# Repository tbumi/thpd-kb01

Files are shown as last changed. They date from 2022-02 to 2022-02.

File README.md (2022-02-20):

# thpd-kb01

My very first mechanical keyboard designed from scratch!

## PCB

The PCB design files are made with KiCad v5.1.12.

### Features

- STM32 Microcontroller (STM32F072C8T6)
- Rotary encoder
- USB-C connector
- NHD-C12832A1Z (128x32 LCD) display (not confirmed working)

## Case

The case files are made with Inkscape. They are available in the `case/` subdirectory.

## License

Licensed under the CERN Open Hardware Licence Version 2 - Strongly Reciprocal. A copy of
the license is included in this repository.

## Firmware

This keyboard uses the QMK firmware. See the firmware in the fork here:
https://github.com/tbumi/qmk_firmware/tree/thpd-kb01/keyboards/thpd_kb01

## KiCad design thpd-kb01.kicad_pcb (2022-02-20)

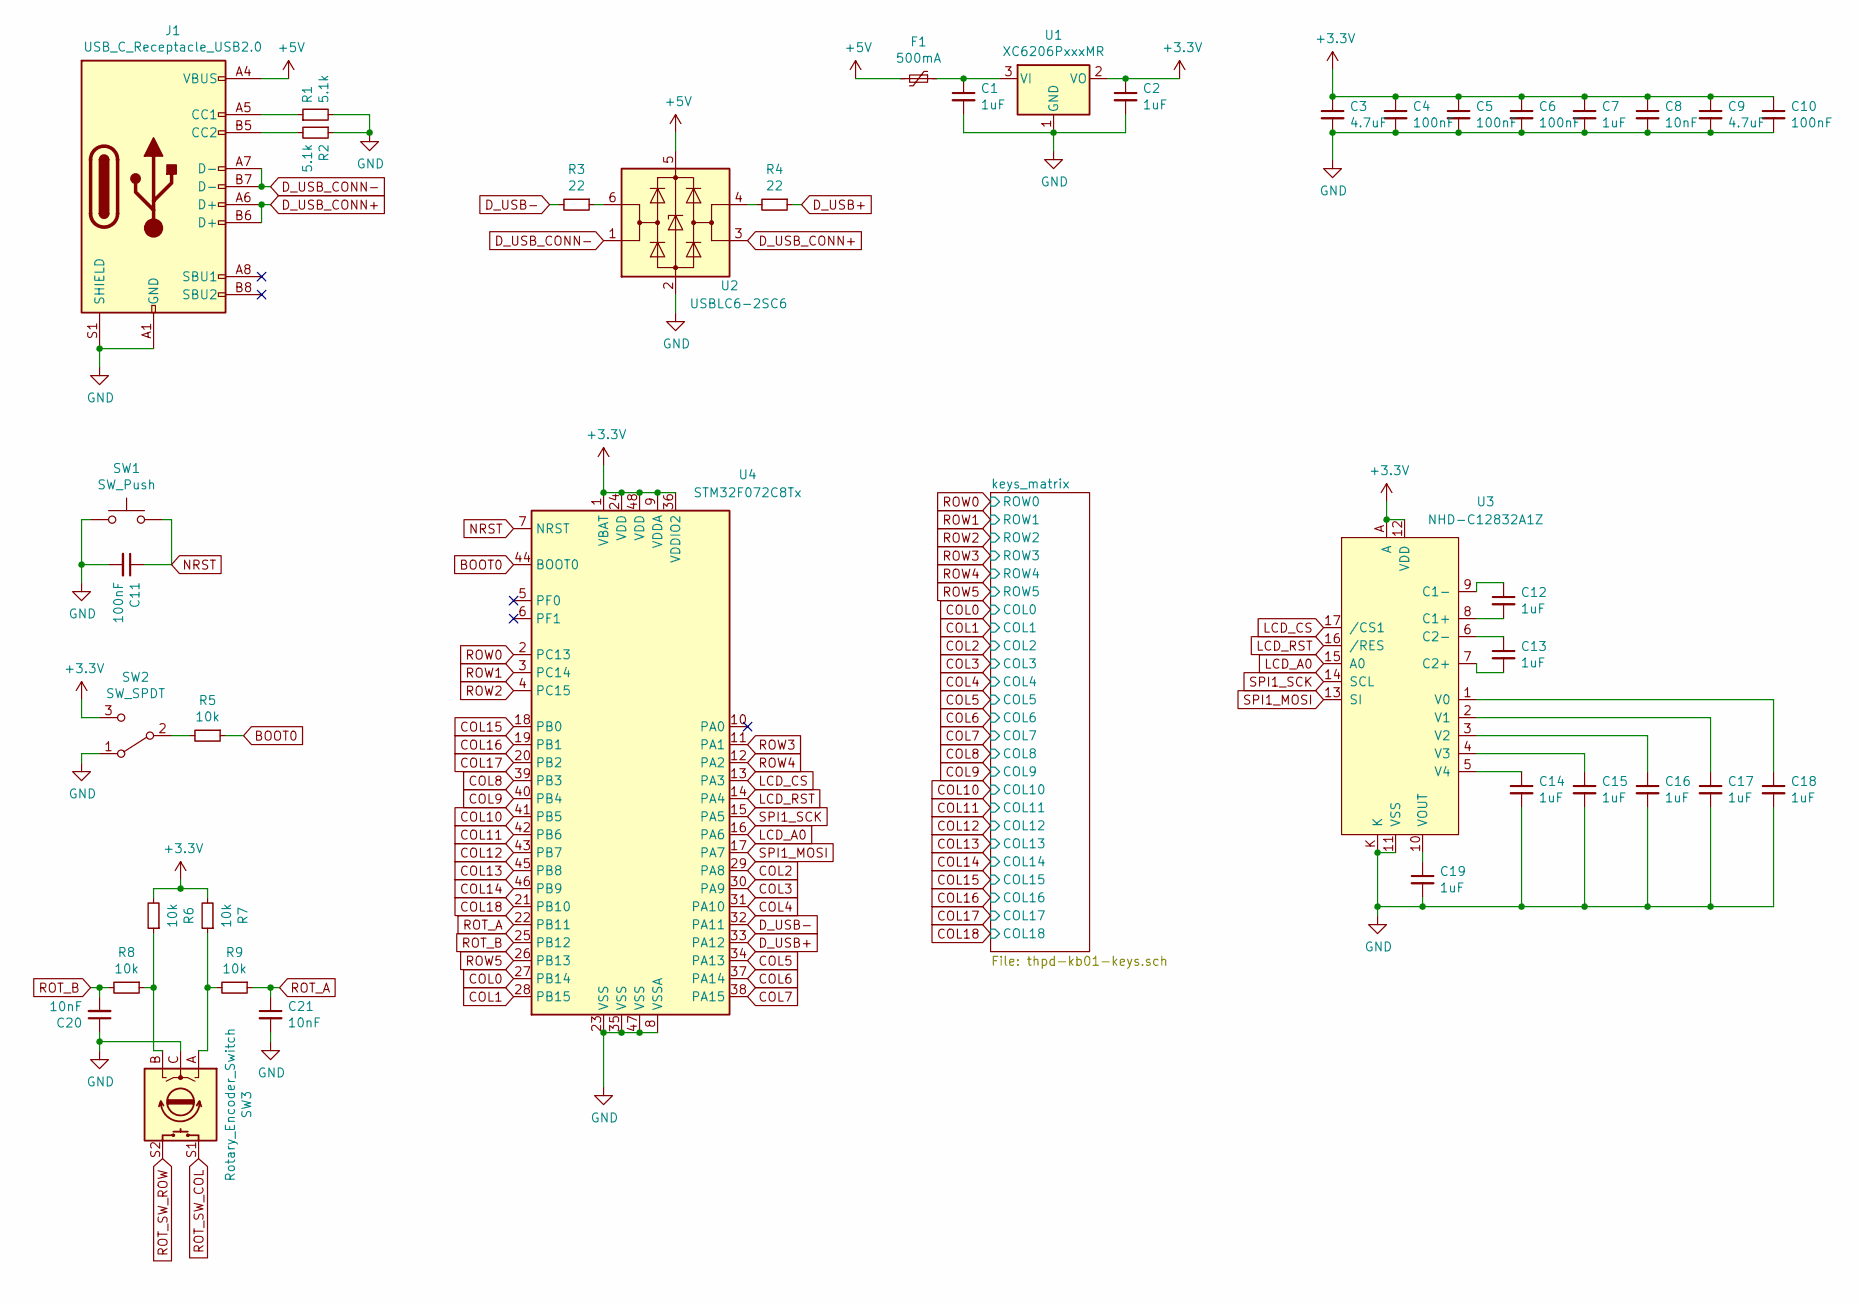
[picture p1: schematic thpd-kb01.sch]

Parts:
C1, C2, C7, C12, C13, C14, C15, C16, C17, C18, C19: 1uF; C_0402_1005Metric; LCSC Part # C52923
C3, C9: 4.7uF; C_0402_1005Metric; LCSC Part # C23733
C4, C5, C6, C10, C11: 100nF; C_0402_1005Metric; LCSC Part # C1525
C8, C20, C21: 10nF; C_0402_1005Metric; LCSC Part # C15195
F1: 500mA; Fuse_0603_1608Metric; LCSC Part # C135321
J1: USB_C_Receptacle_USB2.0; USB_C_Receptacle_HRO_TYPE-C-31-M-12; LCSC Part # C165948
R1, R2: 5.1k; R_0402_1005Metric; LCSC Part # C25905
R3, R4: 22; R_0402_1005Metric; LCSC Part # C25092
R5, R6, R7, R8, R9: 10k; R_0603_1608Metric; LCSC Part # C25804
SW1: SW_Push; SW_Push_SPST_NO_Alps_SKRK; LCSC Part # C202388
SW2: SW_SPDT; SW_SPDT_K3-1296S-E1; LCSC Part # C128955
SW3: Rotary_Encoder_Switch; RotaryEncoder_Alps_EC11E-Switch_Vertical_H20mm
U1: XC6206PxxxMR; SOT-23; LCSC Part # C5446
U2: USBLC6-2SC6; SOT-23-6; LCSC Part # C2827654
U3: NHD-C12832A1Z
U4: STM32F072C8Tx; LQFP-48_7x7mm_P0.5mm

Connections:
+3V3: C2.1, C3.1, C4.1, C5.1, C6.1, C7.1, C8.1, C9.1, C10.1, R6.2, R7.2, SW2.3 (C), U1.2 (VO), U3.12 (VDD), U3.A, U4.1 (VBAT), U4.9 (VDDA), U4.24 (VDD), U4.36 (VDDIO2), U4.48 (VDD)
+5V: F1.2, J1.A4 (VBUS), J1.A9 (VBUS), J1.B4 (VBUS), J1.B9 (VBUS), U2.5 (VBUS)
BOOT0: R5.1, U4.44 (BOOT0)
COL0: U4.27 (PB14); also elsewhere on the board
COL1: U4.28 (PB15); also elsewhere on the board
COL2: U4.29 (PA8); also elsewhere on the board
COL3: U4.30 (PA9); also elsewhere on the board
COL4: U4.31 (PA10); also elsewhere on the board
COL5: U4.34 (PA13); also elsewhere on the board
COL6: U4.37 (PA14); also elsewhere on the board
COL7: U4.38 (PA15); also elsewhere on the board
COL8: U4.39 (PB3); also elsewhere on the board
COL9: U4.40 (PB4); also elsewhere on the board
COL10: U4.41 (PB5); also elsewhere on the board
COL11: U4.42 (PB6); also elsewhere on the board
COL12: U4.43 (PB7); also elsewhere on the board
COL13: U4.45 (PB8); also elsewhere on the board
COL14: U4.46 (PB9); also elsewhere on the board
COL15: U4.18 (PB0); also elsewhere on the board
COL16: U4.19 (PB1); also elsewhere on the board
COL17: U4.20 (PB2); also elsewhere on the board
COL18: SW3.S1, U4.21 (PB10); also elsewhere on the board
D_USB+: R4.1, U4.33 (PA12)
D_USB-: R3.2, U4.32 (PA11)
D_USB_CONN+: J1.A6 (D+), J1.B6 (D+), U2.3 (I/O2)
D_USB_CONN-: J1.A7 (D-), J1.B7 (D-), U2.1 (I/O1)
GND: C1.2, C2.2, C3.2, C4.2, C5.2, C6.2, C7.2, C8.2, C9.2, C10.2, C11.2, C14.2, C15.2, C16.2, C17.2, C18.2, C19.2, C20.1, C21.2, J1.A1 (GND), J1.A12 (GND), J1.B1 (GND), J1.B12 (GND), J1.S1 (SHIELD), R1.2, R2.1, SW1.1, SW2.1 (A), SW3.C, U1.1 (GND), U2.2 (GND), U3.11 (VSS), U3.K, U4.8 (VSSA), U4.23 (VSS), U4.35 (VSS), U4.47 (VSS)
LCD_A0: U3.15 (A0), U4.16 (PA6)
LCD_CS: U3.17 (/CS1), U4.13 (PA3)
LCD_RST: U3.16 (/RES), U4.14 (PA4)
NRST: C11.1, SW1.2, U4.7 (NRST)
unnamed: C1.1, F1.1, U1.3 (VI)
unnamed: C12.1, U3.9 (C1-)
unnamed: C12.2, U3.8 (C1+)
unnamed: C13.1, U3.6 (C2-)
unnamed: C13.2, U3.7 (C2+)
unnamed: C14.1, U3.5 (V4)
unnamed: C15.1, U3.4 (V3)
unnamed: C16.1, U3.3 (V2)
unnamed: C17.1, U3.2 (V1)
unnamed: C18.1, U3.1 (V0)
unnamed: C19.1, U3.10 (VOUT)
unnamed: J1.A5 (CC1), R1.1
unnamed: J1.B5 (CC2), R2.2
unnamed: R3.1, U2.6 (I/O1)
unnamed: R4.2, U2.4 (I/O2)
unnamed: R5.2, SW2.2 (B)
unnamed: R6.1, R8.1, SW3.B
unnamed: R7.1, R9.2, SW3.A
ROT_A: C21.1, R9.1, U4.22 (PB11)
ROT_B: C20.2, R8.2, U4.25 (PB12)
ROT_SW_ROW: SW3.S2; also elsewhere on the board
ROW0: U4.2 (PC13); also elsewhere on the board
ROW1: U4.3 (PC14); also elsewhere on the board
ROW2: U4.4 (PC15); also elsewhere on the board
ROW3: U4.11 (PA1); also elsewhere on the board
ROW4: U4.12 (PA2); also elsewhere on the board
ROW5: U4.26 (PB13); also elsewhere on the board
SPI1_MOSI: U3.13 (SI), U4.17 (PA7)
SPI1_SCK: U3.14 (SCL), U4.15 (PA5)

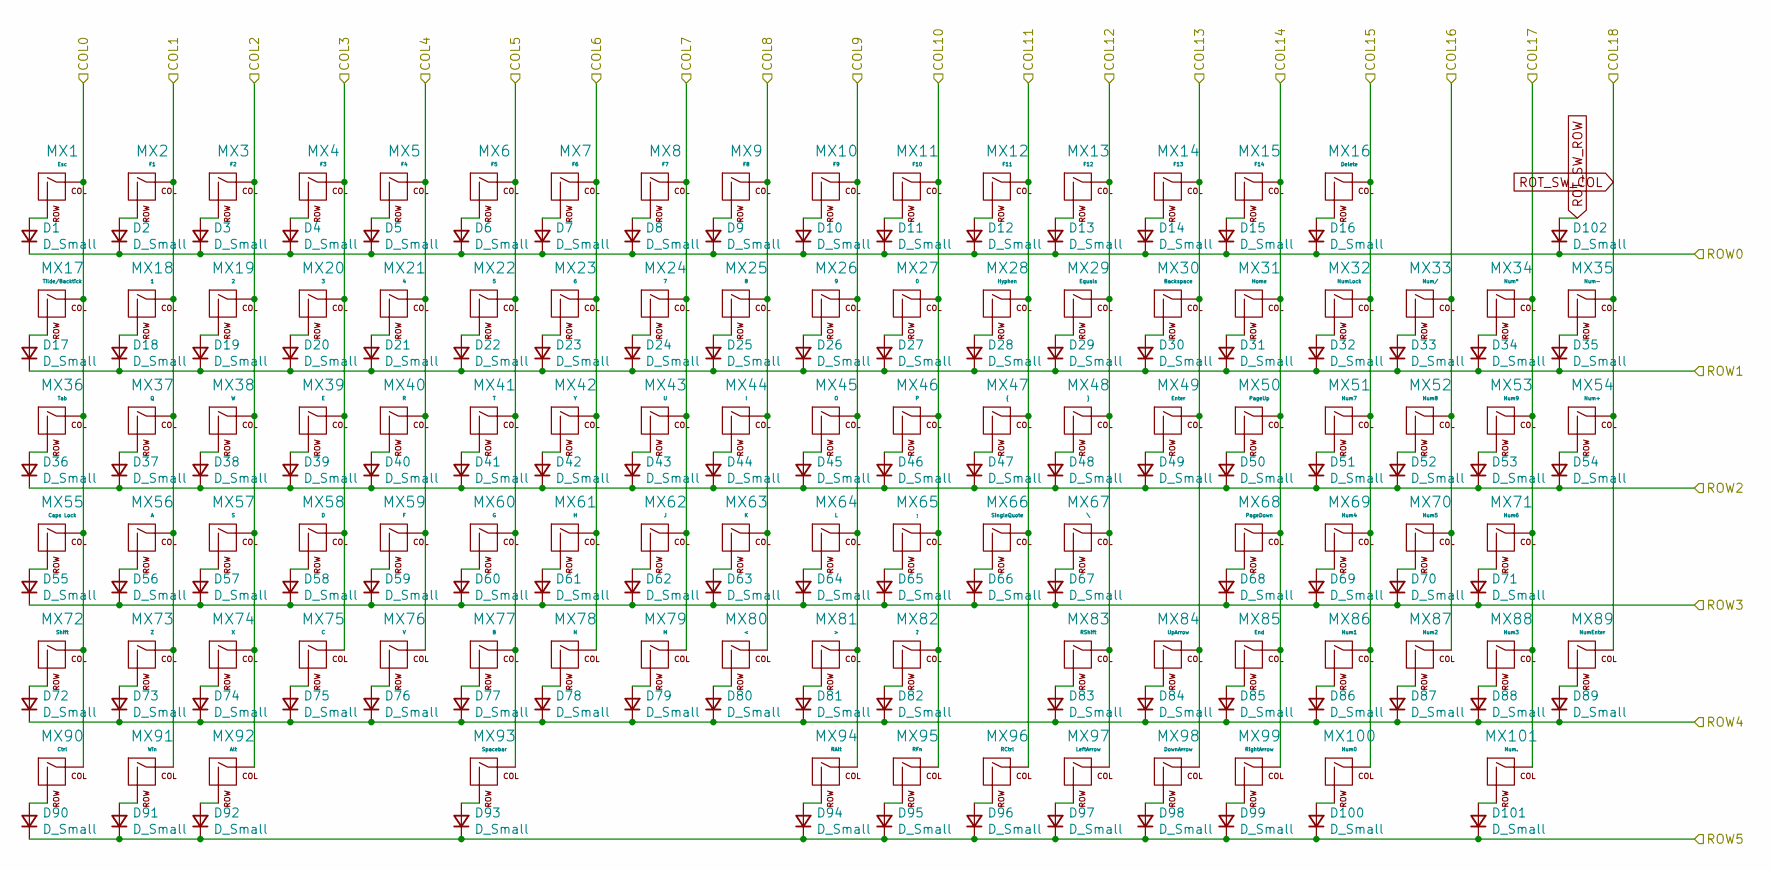
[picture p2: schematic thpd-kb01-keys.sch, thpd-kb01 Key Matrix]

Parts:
D1, D2, D3, D4, D5, D6, D7, D8, D9, D10, D11, D12, D13, D14, D15, D16, D17, D18, D19, D20, D21, D22, D23, D24, D25, D26, D27, D28, D29, D30, D31, D32, D33, D34, D35, D36, D37, D38, D39, D40, D41, D42, D43, D44, D45, D46, D47, D48, D49, D50, D51, D52, D53, D54, D55, D56, D57, D58, D59, D60, D61, D62, D63, D64, D65, D66, D67, D68, D69, D70, D71, D72, D73, D74, D75, D76, D77, D78, D79, D80, D81, D82, D83, D84, D85, D86, D87, D88, D89, D90, D91, D92, D93, D94, D95, D96, D97, D98, D99, D100, D101, D102: D_Small; D_SOD-123; LCSC Part # C81598
MX1: Esc; SW_Cherry_MX_1.00u_Plate
MX2: F1; SW_Cherry_MX_1.00u_Plate
MX3: F2; SW_Cherry_MX_1.00u_Plate
MX4: F3; SW_Cherry_MX_1.00u_Plate
MX5: F4; SW_Cherry_MX_1.00u_Plate
MX6: F5; SW_Cherry_MX_1.00u_Plate
MX7: F6; SW_Cherry_MX_1.00u_Plate
MX8: F7; SW_Cherry_MX_1.00u_Plate
MX9: F8; SW_Cherry_MX_1.00u_Plate
MX10: F9; SW_Cherry_MX_1.00u_Plate
MX11: F10; SW_Cherry_MX_1.00u_Plate
MX12: F11; SW_Cherry_MX_1.00u_Plate
MX13: F12; SW_Cherry_MX_1.00u_Plate
MX14: F13; SW_Cherry_MX_1.00u_Plate
MX15: F14; SW_Cherry_MX_1.00u_Plate
MX16: Delete; SW_Cherry_MX_1.00u_Plate
MX17: Tilde/Backtick; SW_Cherry_MX_1.00u_Plate
MX18: 1; SW_Cherry_MX_1.00u_Plate
MX19: 2; SW_Cherry_MX_1.00u_Plate
MX20: 3; SW_Cherry_MX_1.00u_Plate
MX21: 4; SW_Cherry_MX_1.00u_Plate
MX22: 5; SW_Cherry_MX_1.00u_Plate
MX23: 6; SW_Cherry_MX_1.00u_Plate
MX24: 7; SW_Cherry_MX_1.00u_Plate
MX25: 8; SW_Cherry_MX_1.00u_Plate
MX26: 9; SW_Cherry_MX_1.00u_Plate
MX27: 0; SW_Cherry_MX_1.00u_Plate
MX28: Hyphen; SW_Cherry_MX_1.00u_Plate
MX29: Equals; SW_Cherry_MX_1.00u_Plate
MX30: Backspace; SW_Cherry_MX_2.00u_Plate
MX31: Home; SW_Cherry_MX_1.00u_Plate
MX32: NumLock; SW_Cherry_MX_1.00u_Plate
MX33: Num/; SW_Cherry_MX_1.00u_Plate
MX34: Num*; SW_Cherry_MX_1.00u_Plate
MX35: Num-; SW_Cherry_MX_1.00u_Plate
MX36: Tab; SW_Cherry_MX_1.50u_Plate
MX37: Q; SW_Cherry_MX_1.00u_Plate
MX38: W; SW_Cherry_MX_1.00u_Plate
MX39: E; SW_Cherry_MX_1.00u_Plate
MX40: R; SW_Cherry_MX_1.00u_Plate
MX41: T; SW_Cherry_MX_1.00u_Plate
MX42: Y; SW_Cherry_MX_1.00u_Plate
MX43: U; SW_Cherry_MX_1.00u_Plate
MX44: I; SW_Cherry_MX_1.00u_Plate
MX45: O; SW_Cherry_MX_1.00u_Plate
MX46: P; SW_Cherry_MX_1.00u_Plate
MX47: {; SW_Cherry_MX_1.00u_Plate
MX48: }; SW_Cherry_MX_1.00u_Plate
MX49: Enter; SW_Cherry_MX_ISOEnter_Plate
MX50: PageUp; SW_Cherry_MX_1.00u_Plate
MX51: Num7; SW_Cherry_MX_1.00u_Plate
MX52: Num8; SW_Cherry_MX_1.00u_Plate
MX53: Num9; SW_Cherry_MX_1.00u_Plate
MX54: Num+; SW_Cherry_MX_2.00u_Vertical_Plate
MX55: Caps Lock; SW_Cherry_MX_1.75u_Plate
MX56: A; SW_Cherry_MX_1.00u_Plate
MX57: S; SW_Cherry_MX_1.00u_Plate
MX58: D; SW_Cherry_MX_1.00u_Plate
MX59: F; SW_Cherry_MX_1.00u_Plate
MX60: G; SW_Cherry_MX_1.00u_Plate
MX61: H; SW_Cherry_MX_1.00u_Plate
MX62: J; SW_Cherry_MX_1.00u_Plate
MX63: K; SW_Cherry_MX_1.00u_Plate
MX64: L; SW_Cherry_MX_1.00u_Plate
MX65: ;; SW_Cherry_MX_1.00u_Plate
MX66: SingleQuote; SW_Cherry_MX_1.00u_Plate
MX67: \\; SW_Cherry_MX_1.00u_Plate
MX68: PageDown; SW_Cherry_MX_1.00u_Plate
MX69: Num4; SW_Cherry_MX_1.00u_Plate
MX70: Num5; SW_Cherry_MX_1.00u_Plate
MX71: Num6; SW_Cherry_MX_1.00u_Plate
MX72: Shift; SW_Cherry_MX_2.25u_Plate
MX73: Z; SW_Cherry_MX_1.00u_Plate
MX74: X; SW_Cherry_MX_1.00u_Plate
MX75: C; SW_Cherry_MX_1.00u_Plate
MX76: V; SW_Cherry_MX_1.00u_Plate
MX77: B; SW_Cherry_MX_1.00u_Plate
MX78: N; SW_Cherry_MX_1.00u_Plate
MX79: M; SW_Cherry_MX_1.00u_Plate
MX80: <; SW_Cherry_MX_1.00u_Plate
MX81: >; SW_Cherry_MX_1.00u_Plate
MX82: ?; SW_Cherry_MX_1.00u_Plate
MX83: RShift; SW_Cherry_MX_1.75u_Plate
MX84: UpArrow; SW_Cherry_MX_1.00u_Plate
MX85: End; SW_Cherry_MX_1.00u_Plate
MX86: Num1; SW_Cherry_MX_1.00u_Plate
MX87: Num2; SW_Cherry_MX_1.00u_Plate
MX88: Num3; SW_Cherry_MX_1.00u_Plate
MX89: NumEnter; SW_Cherry_MX_2.00u_Vertical_Plate
MX90: Ctrl; SW_Cherry_MX_1.25u_Plate
MX91: Win; SW_Cherry_MX_1.25u_Plate
MX92: Alt; SW_Cherry_MX_1.25u_Plate
MX93: Spacebar; SW_Cherry_MX_6.25u_Plate
MX94: RAlt; SW_Cherry_MX_1.00u_Plate
MX95: RFn; SW_Cherry_MX_1.00u_Plate
MX96: RCtrl; SW_Cherry_MX_1.00u_Plate
MX97: LeftArrow; SW_Cherry_MX_1.00u_Plate
MX98: DownArrow; SW_Cherry_MX_1.00u_Plate
MX99: RightArrow; SW_Cherry_MX_1.00u_Plate
MX100: Num0; SW_Cherry_MX_2.00u_Plate
MX101: Num.; SW_Cherry_MX_1.00u_Plate

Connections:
COL0: MX1.1 (COL), MX17.1 (COL), MX36.1 (COL), MX55.1 (COL), MX72.1 (COL), MX90.1 (COL); also elsewhere on the board
COL1: MX2.1 (COL), MX18.1 (COL), MX37.1 (COL), MX56.1 (COL), MX73.1 (COL), MX91.1 (COL); also elsewhere on the board
COL2: MX3.1 (COL), MX19.1 (COL), MX38.1 (COL), MX57.1 (COL), MX74.1 (COL), MX92.1 (COL); also elsewhere on the board
COL3: MX4.1 (COL), MX20.1 (COL), MX39.1 (COL), MX58.1 (COL), MX75.1 (COL); also elsewhere on the board
COL4: MX5.1 (COL), MX21.1 (COL), MX40.1 (COL), MX59.1 (COL), MX76.1 (COL); also elsewhere on the board
COL5: MX6.1 (COL), MX22.1 (COL), MX41.1 (COL), MX60.1 (COL), MX77.1 (COL), MX93.1 (COL); also elsewhere on the board
COL6: MX7.1 (COL), MX23.1 (COL), MX42.1 (COL), MX61.1 (COL), MX78.1 (COL); also elsewhere on the board
COL7: MX8.1 (COL), MX24.1 (COL), MX43.1 (COL), MX62.1 (COL), MX79.1 (COL); also elsewhere on the board
COL8: MX9.1 (COL), MX25.1 (COL), MX44.1 (COL), MX63.1 (COL), MX80.1 (COL); also elsewhere on the board
COL9: MX10.1 (COL), MX26.1 (COL), MX45.1 (COL), MX64.1 (COL), MX81.1 (COL), MX94.1 (COL); also elsewhere on the board
COL10: MX11.1 (COL), MX27.1 (COL), MX46.1 (COL), MX65.1 (COL), MX82.1 (COL), MX95.1 (COL); also elsewhere on the board
COL11: MX12.1 (COL), MX28.1 (COL), MX47.1 (COL), MX66.1 (COL), MX96.1 (COL); also elsewhere on the board
COL12: MX13.1 (COL), MX29.1 (COL), MX48.1 (COL), MX67.1 (COL), MX83.1 (COL), MX97.1 (COL); also elsewhere on the board
COL13: MX14.1 (COL), MX30.1 (COL), MX49.1 (COL), MX84.1 (COL), MX98.1 (COL); also elsewhere on the board
COL14: MX15.1 (COL), MX31.1 (COL), MX50.1 (COL), MX68.1 (COL), MX85.1 (COL), MX99.1 (COL); also elsewhere on the board
COL15: MX16.1 (COL), MX32.1 (COL), MX51.1 (COL), MX69.1 (COL), MX86.1 (COL), MX100.1 (COL); also elsewhere on the board
COL16: MX33.1 (COL), MX52.1 (COL), MX70.1 (COL), MX87.1 (COL); also elsewhere on the board
COL17: MX34.1 (COL), MX53.1 (COL), MX71.1 (COL), MX88.1 (COL), MX101.1 (COL); also elsewhere on the board
COL18: MX35.1 (COL), MX54.1 (COL), MX89.1 (COL); also elsewhere on the board
unnamed: D1.2 (A), MX1.2 (ROW)
unnamed: D2.2 (A), MX2.2 (ROW)
unnamed: D3.2 (A), MX3.2 (ROW)
unnamed: D4.2 (A), MX4.2 (ROW)
unnamed: D5.2 (A), MX5.2 (ROW)
unnamed: D6.2 (A), MX6.2 (ROW)
unnamed: D7.2 (A), MX7.2 (ROW)
unnamed: D8.2 (A), MX8.2 (ROW)
unnamed: D9.2 (A), MX9.2 (ROW)
unnamed: D10.2 (A), MX10.2 (ROW)
unnamed: D11.2 (A), MX11.2 (ROW)
unnamed: D12.2 (A), MX12.2 (ROW)
unnamed: D13.2 (A), MX13.2 (ROW)
unnamed: D14.2 (A), MX14.2 (ROW)
unnamed: D15.2 (A), MX15.2 (ROW)
unnamed: D16.2 (A), MX16.2 (ROW)
unnamed: D17.2 (A), MX17.2 (ROW)
unnamed: D18.2 (A), MX18.2 (ROW)
unnamed: D19.2 (A), MX19.2 (ROW)
unnamed: D20.2 (A), MX20.2 (ROW)
unnamed: D21.2 (A), MX21.2 (ROW)
unnamed: D22.2 (A), MX22.2 (ROW)
unnamed: D23.2 (A), MX23.2 (ROW)
unnamed: D24.2 (A), MX24.2 (ROW)
unnamed: D25.2 (A), MX25.2 (ROW)
unnamed: D26.2 (A), MX26.2 (ROW)
unnamed: D27.2 (A), MX27.2 (ROW)
unnamed: D28.2 (A), MX28.2 (ROW)
unnamed: D29.2 (A), MX29.2 (ROW)
unnamed: D30.2 (A), MX30.2 (ROW)
unnamed: D31.2 (A), MX31.2 (ROW)
unnamed: D32.2 (A), MX32.2 (ROW)
unnamed: D33.2 (A), MX33.2 (ROW)
unnamed: D34.2 (A), MX34.2 (ROW)
unnamed: D35.2 (A), MX35.2 (ROW)
unnamed: D36.2 (A), MX36.2 (ROW)
unnamed: D37.2 (A), MX37.2 (ROW)
unnamed: D38.2 (A), MX38.2 (ROW)
unnamed: D39.2 (A), MX39.2 (ROW)
unnamed: D40.2 (A), MX40.2 (ROW)
unnamed: D41.2 (A), MX41.2 (ROW)
unnamed: D42.2 (A), MX42.2 (ROW)
unnamed: D43.2 (A), MX43.2 (ROW)
unnamed: D44.2 (A), MX44.2 (ROW)
unnamed: D45.2 (A), MX45.2 (ROW)
unnamed: D46.2 (A), MX46.2 (ROW)
unnamed: D47.2 (A), MX47.2 (ROW)
unnamed: D48.2 (A), MX48.2 (ROW)
unnamed: D49.2 (A), MX49.2 (ROW)
unnamed: D50.2 (A), MX50.2 (ROW)
unnamed: D51.2 (A), MX51.2 (ROW)
unnamed: D52.2 (A), MX52.2 (ROW)
unnamed: D53.2 (A), MX53.2 (ROW)
unnamed: D54.2 (A), MX54.2 (ROW)
unnamed: D55.2 (A), MX55.2 (ROW)
unnamed: D56.2 (A), MX56.2 (ROW)
unnamed: D57.2 (A), MX57.2 (ROW)
unnamed: D58.2 (A), MX58.2 (ROW)
unnamed: D59.2 (A), MX59.2 (ROW)
unnamed: D60.2 (A), MX60.2 (ROW)
unnamed: D61.2 (A), MX61.2 (ROW)
unnamed: D62.2 (A), MX62.2 (ROW)
unnamed: D63.2 (A), MX63.2 (ROW)
unnamed: D64.2 (A), MX64.2 (ROW)
unnamed: D65.2 (A), MX65.2 (ROW)
unnamed: D66.2 (A), MX66.2 (ROW)
unnamed: D67.2 (A), MX67.2 (ROW)
unnamed: D68.2 (A), MX68.2 (ROW)
unnamed: D69.2 (A), MX69.2 (ROW)
unnamed: D70.2 (A), MX70.2 (ROW)
unnamed: D71.2 (A), MX71.2 (ROW)
unnamed: D72.2 (A), MX72.2 (ROW)
unnamed: D73.2 (A), MX73.2 (ROW)
unnamed: D74.2 (A), MX74.2 (ROW)
unnamed: D75.2 (A), MX75.2 (ROW)
unnamed: D76.2 (A), MX76.2 (ROW)
unnamed: D77.2 (A), MX77.2 (ROW)
unnamed: D78.2 (A), MX78.2 (ROW)
unnamed: D79.2 (A), MX79.2 (ROW)
unnamed: D80.2 (A), MX80.2 (ROW)
unnamed: D81.2 (A), MX81.2 (ROW)
unnamed: D82.2 (A), MX82.2 (ROW)
unnamed: D83.2 (A), MX83.2 (ROW)
unnamed: D84.2 (A), MX84.2 (ROW)
unnamed: D85.2 (A), MX85.2 (ROW)
unnamed: D86.2 (A), MX86.2 (ROW)
unnamed: D87.2 (A), MX87.2 (ROW)
unnamed: D88.2 (A), MX88.2 (ROW)
unnamed: D89.2 (A), MX89.2 (ROW)
unnamed: D90.2 (A), MX90.2 (ROW)
unnamed: D91.2 (A), MX91.2 (ROW)
unnamed: D92.2 (A), MX92.2 (ROW)
unnamed: D93.2 (A), MX93.2 (ROW)
unnamed: D94.2 (A), MX94.2 (ROW)
unnamed: D95.2 (A), MX95.2 (ROW)
unnamed: D96.2 (A), MX96.2 (ROW)
unnamed: D97.2 (A), MX97.2 (ROW)
unnamed: D98.2 (A), MX98.2 (ROW)
unnamed: D99.2 (A), MX99.2 (ROW)
unnamed: D100.2 (A), MX100.2 (ROW)
unnamed: D101.2 (A), MX101.2 (ROW)
ROT_SW_ROW: D102.2 (A); also elsewhere on the board
ROW0: D1.1 (K), D2.1 (K), D3.1 (K), D4.1 (K), D5.1 (K), D6.1 (K), D7.1 (K), D8.1 (K), D9.1 (K), D10.1 (K), D11.1 (K), D12.1 (K), D13.1 (K), D14.1 (K), D15.1 (K), D16.1 (K), D102.1 (K); also elsewhere on the board
ROW1: D17.1 (K), D18.1 (K), D19.1 (K), D20.1 (K), D21.1 (K), D22.1 (K), D23.1 (K), D24.1 (K), D25.1 (K), D26.1 (K), D27.1 (K), D28.1 (K), D29.1 (K), D30.1 (K), D31.1 (K), D32.1 (K), D33.1 (K), D34.1 (K), D35.1 (K); also elsewhere on the board
ROW2: D36.1 (K), D37.1 (K), D38.1 (K), D39.1 (K), D40.1 (K), D41.1 (K), D42.1 (K), D43.1 (K), D44.1 (K), D45.1 (K), D46.1 (K), D47.1 (K), D48.1 (K), D49.1 (K), D50.1 (K), D51.1 (K), D52.1 (K), D53.1 (K), D54.1 (K); also elsewhere on the board
ROW3: D55.1 (K), D56.1 (K), D57.1 (K), D58.1 (K), D59.1 (K), D60.1 (K), D61.1 (K), D62.1 (K), D63.1 (K), D64.1 (K), D65.1 (K), D66.1 (K), D67.1 (K), D68.1 (K), D69.1 (K), D70.1 (K), D71.1 (K); also elsewhere on the board
ROW4: D72.1 (K), D73.1 (K), D74.1 (K), D75.1 (K), D76.1 (K), D77.1 (K), D78.1 (K), D79.1 (K), D80.1 (K), D81.1 (K), D82.1 (K), D83.1 (K), D84.1 (K), D85.1 (K), D86.1 (K), D87.1 (K), D88.1 (K), D89.1 (K); also elsewhere on the board
ROW5: D90.1 (K), D91.1 (K), D92.1 (K), D93.1 (K), D94.1 (K), D95.1 (K), D96.1 (K), D97.1 (K), D98.1 (K), D99.1 (K), D100.1 (K), D101.1 (K); also elsewhere on the board

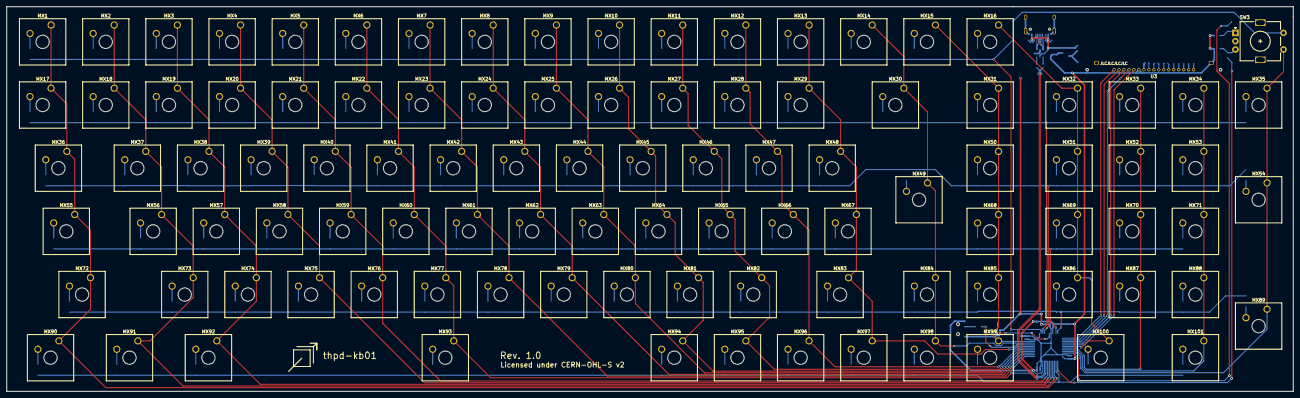
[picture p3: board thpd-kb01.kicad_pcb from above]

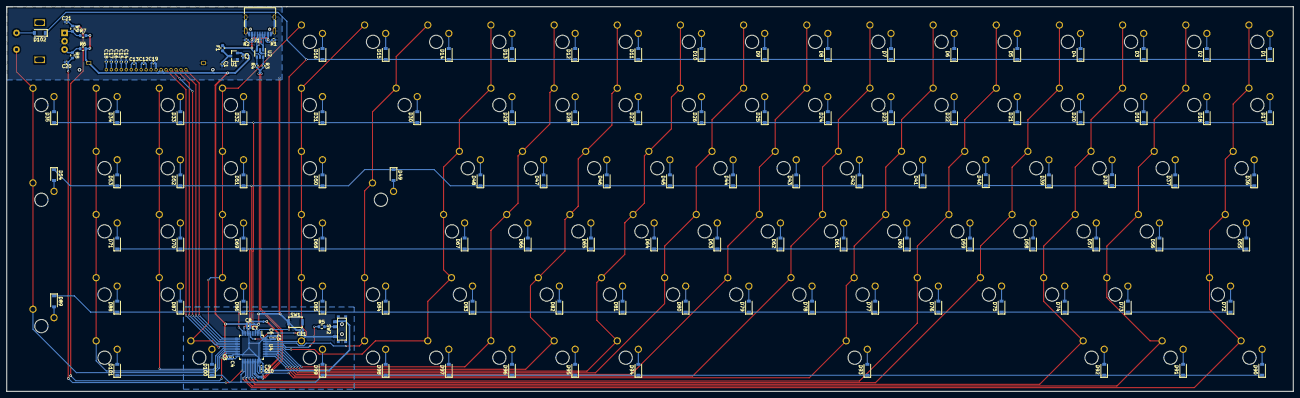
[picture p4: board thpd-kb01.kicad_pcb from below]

Board: 2 copper layers, 388.0 x 116.0 mm, 242 parts (139 on the bottom side), 161 nets.

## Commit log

2021-10-23 init project
    [thpd-kb01.kicad_pcb, thpd-kb01.sch]
2021-10-23 WIP keys matrix
    [thpd-kb01-keys.sch, thpd-kb01.sch]
2021-10-25 wip pcb
    [thpd-kb01-keys.sch, thpd-kb01.kicad_pcb]
2021-10-31 Switch USB B to USB C
    [thpd-kb01.kicad_pcb, thpd-kb01.sch]
2021-11-07 remove random-keyboard-parts from kicad
2021-11-18 Switch to STM32F072CBT6 MCU
    [thpd-kb01.sch]
2021-11-18 re-annotate symbols
    [thpd-kb01-keys.sch, thpd-kb01.sch]
2021-12-04 Big changes
    [thpd-kb01-keys.sch, thpd-kb01-led.sch, thpd-kb01.kicad_pcb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]
2021-12-12 All routing except row/col done.
    [thpd-kb01.kicad_pcb]
2021-12-15 Routing of rows and columns done.
    [thpd-kb01.kicad_pcb, thpd-kb01.sch]
2021-12-20 All routing complete.
    [thpd-kb01.kicad_pcb]
2021-12-20 Add art.
    [thpd-kb01.kicad_pcb]
2021-12-20 Add LCSC part numbers and prepared for output.
    [thpd-kb01-keys.sch, thpd-kb01-led.sch, thpd-kb01.kicad_pcb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]
2022-01-04 Remove LEDs and redo routing from scratch.
    [thpd-kb01-keys.sch, thpd-kb01.kicad_pcb, thpd-kb01.sch]
2022-01-06 All DRC errors corrected.
    [thpd-kb01.kicad_pcb]
2022-01-06 Final release to production.
    [thpd-kb01.kicad_pcb]
2022-01-30 Case drafts (WIP)
2022-01-31 Case ready to print.
2022-02-12 Fix 5mm print file
2022-02-20 Add license text to KiCad sources.
    [thpd-kb01.kicad_pcb, thpd-kb01.sch]

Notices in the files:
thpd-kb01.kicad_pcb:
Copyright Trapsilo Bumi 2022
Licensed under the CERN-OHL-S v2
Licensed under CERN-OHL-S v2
